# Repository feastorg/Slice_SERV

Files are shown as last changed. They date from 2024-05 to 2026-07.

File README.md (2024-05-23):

<div align="center">
  <!-- Title: -->
  <a href="https://github.com/uwo-fast">
    
  </a>
  <h2><a href="https://github.com/uwo-fast/Slice_SERV"> SERV Slice </a></h2>
  <!-- Labels: -->
  <!-- First row: -->
  <a href="https://github.com/uwo-fast/.github/blob/main/collaborating.md">
    
  </a>
  <a href="https://github.com/uwo-fast/.github/blob/main/contributing.md">
    
  </a>
  <a href="https://www.appropedia.org/Category:FAST_literature_reviews">
    
  </a>
  <a href="https://certification.oshwa.org/">
    
    <!-- img src="https://img.shields.io/badge/OSHWA-Certified-darkgreen?style=flat-square" height="20" alt="OSHWA" -->       <!-- img src="https://img.shields.io/badge/OSHWA-Pending-darkorange?style=flat-square" height="20" alt="OSHWA" -->
  </a>
  <a href="https://osf.io/">
    
  </a>
  <a href="https://doi.org">
    
  </a>
  <!-- Second row: -->
  <br>
  <a href="https://github.com/uwo-fast/Slice_SERV/blob/main/LICENSE">
    
  </a>
  <a href="https://github.com/uwo-fast/Slice_SERV">
    
  </a>
  <a href="https://github.com/uwo-fast/Slice_SERV/issues">
    
  </a>
  <a href="https://github.com/uwo-fast/Slice_SERV/network/members">
    
  </a>
  <a href="https://github.com/uwo-fast/Slice_SERV/stargazers">
    
  </a>
  <!-- Short description: -->
  <h3>Servo Motor Control Slice for BREAD.</h3>
</div>

## Introduction
[Provide a brief introduction to the project, including the motivation and goals. Explain the significance and context of the research.]

## Project Overview
[Describe the project in more detail. This section can be split into subsections if necessary.]

## Installation
[Provide instructions for installing any necessary software or hardware components.]

## Usage
[Explain how to use the project. Include examples and screenshots if applicable.]

### Basic Usage
[Provide basic usage instructions.]

### Advanced Usage
[Provide advanced usage instructions, including any optional features or configurations.]

## Documentation
[Link to the detailed documentation if available. Provide instructions on how to access and navigate the documentation.]

## Contributing
[Explain how others can contribute to the project. Include guidelines for submitting issues, pull requests, and any coding standards.]

### Code of Conduct
[Link to the project's code of conduct if available.]

## License
[State the license under which the project is distributed. Include a link to the full license text.]

## Acknowledgements
[Acknowledge any contributors, collaborators, funding sources, or organizations that supported the project.]

## Contact
[Provide contact information for the project maintainer(s) or lead researcher(s). Include an email address or a link to a contact form.]

---

<div align="center">
  <p>
    
    
  </p>
</div>

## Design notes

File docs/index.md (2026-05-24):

---
title: "Slice SERV Documentation"
description: "Overview and entry page for Slice SERV project documentation."
nav_exclude: true
---

Welcome to the Slice SERV project documentation.

## Board Renders

<figure style="display:inline-block; text-align:center; margin:10px;">
  Board Top
  <figcaption>Top</figcaption>
</figure>

<figure style="display:inline-block; text-align:center; margin:10px;">
  Board Bottom
  <figcaption>Bottom</figcaption>
</figure>

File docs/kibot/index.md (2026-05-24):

---
title: "KiBot Outputs"
description: "Index for KiBot-generated PCB artifacts."
layout: "page"
---

These are the docs & KiBot Outputs for Slice SERV

The following files were generated from the latest PCB build:

- [Schematic.pdf](./Schematic.pdf)
- [PCB.pdf](./PCB.pdf)
- [kibot.log](./kibot.log)
- [BREAD_Slice-bom.html](./BREAD_Slice-bom.html)
- [BREAD_Slice-ibom.html](./BREAD_Slice-ibom.html)

_Last updated automatically by KiBot via GitHub Actions._

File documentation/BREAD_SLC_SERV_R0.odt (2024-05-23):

# Broadly Reconfigurable and Expandable Automation Device (BREAD) – Slice Datasheet: Servo Motor Control Slice (SLC-SERV)

By: Nicholas Whisman (ngwhisma@mtu.edu) – Revision 0, on 18. May 2021

## Short Device Description

This device controls up to 5 Servo motors. As Servo motors have internal feedback control systems, this system thus has no feedback path.

## Quick Information

Device at a Glance

Short title | Servo Motor Control Slice
Part # | SLC-SERV
Repository Link | Link to OSF or other repository
Academic Paper DOI | DOI link to published paper
Device Cost | Monetary cost of the device
Assembly Difficulty | Easy, Millable
Application Area | Robotics, Controlling Machinery

Device Connections

J2 – Servo Motor 1

Pin # | Description | Rating
1 | PWM to Servo | N/A
2 | Voltage Input | Varies by Motor. Terminal can only support 10-15A
3 | GND | N/A

J3 – Servo Motor 2

Pin # | Description | Rating
1 | PWM to Servo | N/A
2 | Voltage Input | Varies by Motor. Terminal can only support 10-15A
3 | GND | N/A

J4 – Servo Motor 3

Pin # | Description | Rating
1 | PWM to Servo | N/A
2 | Voltage Input | Varies by Motor. Terminal can only support 10-15A
3 | GND | N/A

J5 – Servo Motor 4

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

J6 – Servo Motor 5

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

J7 – Power Select

Pin # | Description | Rating
1 | Power Output Pin | MUST connect one of the below to this pin.
2 | Custom Power Input | N/A
3 | Standard 12V | N/A

J8 – Custom Power Input

Pin # | Description | Rating
1 | V + | N/A
2 | GND | N/A

## Commands

Write Angle (no significant returns)
Byte: Address | Bit: 1 | Float: Target Temp | Float: Ramp Rate (d/m)
Set Up (no significant returns)
Byte: Address | Bit: 0 | Float: 0 | Float: 0

## Schematic

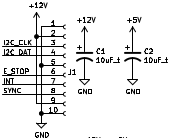
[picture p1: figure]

Figure 1: BREAD Connection Port and Power Capacitors

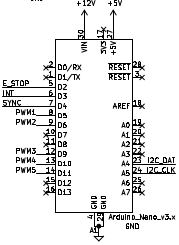
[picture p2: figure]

Figure 2: Arduino Nano

Figure 3: One of five identical Servo connection ports

Figure 4: Power Select Pins

Figure 5: Custom Power Input Port

## Bill of Materials

Designator | Description | Quantity | Cost / part | URL
J8 | 01x02 1/10” Pitch Terminal Block | 1 | 1.27 | https://www.digikey.com/short/792dvv77
J7 | 01x03 1/10” Pitch Connector Pins | 1 | 0.27 | https://www.digikey.com/short/2j42vf3d
J2-J6 | 01x03 1/10” Pitch Terminal Block | 5 | 2.06 | https://www.digikey.com/short/18bph2rj
J1 | 01x10 Female Header Pins | 1 | 0.79 | https://www.digikey.com/short/23bfwwjh
C1-2 | 1206 Packaging 10 µF Capacitor | 2 | 0.64 | https://www.digikey.com/short/qfrbqfhd
A1 | Arduino Nano | 1 | 22.00 | https://www.digikey.com/en/products/detail/arduino/A000005/2638989

## Construction & Fabrication

List any tools that are required and short guide on the order which parts should be soldered / assembled. Be sure to note any specialized methods and point out components that may easily be soldered in the incorrect orientation. Additionally include at least one picture of the assembled board (include both sides if there are components on both sides).

[Image of the assembled Circuit Board]

Fig #. Subtitle should go here.

## Configuration & Calibration

Include a list of default jumper and potentiometer positions:

Hardware Positions

- Turn P1 to be roughly 50%
- Turn P2 to be completely closed (turn clockwise until potentiometer clicks)
- Place a jumper to short out J3. Etc…

Detail any key parameters the end-user may want to adjust in the firmware, and if there are any special instructions before programming the Slice.

Tools Required For Calibration

- An oscilloscope with at least 15Mhz sampling
- A multimeter. Etc…

List all of the tools / instruments required for calibration. Provide a detailed & step by step guide on how to calibrate (or validate) each unique type of channel on the card. Include what variables in the firmware may need to be adjusted (and when). Attach a wiring diagram for each relevant calibration circuit.

[Image of the calibration circuit]

Fig #. Subtitle should go here.

## Usage & Constraints

List the relevant constraints for each type of channel on the card. These parameters may be quantities like max current, max voltage, frequency, sampling frequency, etc.

List an example wiring diagram of the slice in use, as well as some suggested applications

[Image of the example usage wiring diagram]

Fig #. Subtitle should go here.

## General Comments on Slice

This section is intended as a catch-all for any topics that are relevant to the Slice that don’t fit in any other category.

## Revision Notes

- Rev 0 – Initial document release (DATE HERE)

SLC-SERV Datasheet – Revision 0

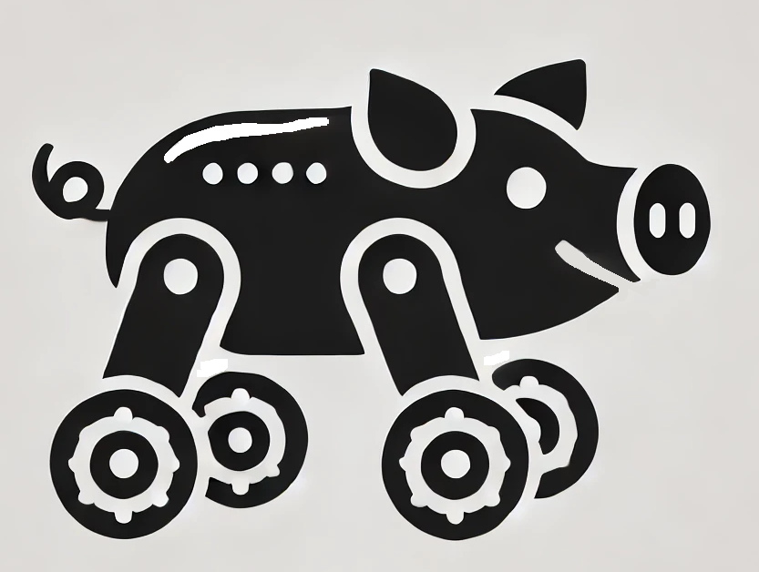
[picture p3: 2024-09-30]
hardware/servo-piggie.png

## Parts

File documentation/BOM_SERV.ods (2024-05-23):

Id | Designator | Package | Quantity | Designation | Supplier and ref
1 | J8 | TerminalBlock_TE_282834-2_1x02_P2.54mm_Horizontal | 1 | Screw_Terminal_01x02 | https://www.digikey.ca/en/products/detail/on-shore-technology-inc/OSTVN02A150/1588862
2 | J7 | PinSocket_1x03_P2.54mm_Vertical | 1 | Conn_01x03_Male | https://www.digikey.ca/en/products/detail/sullins-connector-solutions/PREC003SAAN-RC/2774851
3 | J6,J5,J4,J3,J2 | TerminalBlock_TE_282834-3_1x03_P2.54mm_Horizontal | 5 | Screw_Terminal_01x03 | https://www.digikey.ca/en/products/detail/on-shore-technology-inc/OSTVN03A150/1588863
4 | C1,C2 | C_2312 | 2 | 10uF_t | https://www.digikey.ca/short/qfrbqfhd
5 | A1 | Arduino_Nano | 1 | Arduino_Nano_v3.x | https://www.digikey.ca/en/products/detail/arduino/A000005/2638989
6 | J1 | PinSocket_1x10_P2.54mm_Horizontal | 1 | Conn_01x10_Female | https://www.digikey.ca/en/products/detail/sullins-connector-solutions/PPPC101LGBN-RC/775943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

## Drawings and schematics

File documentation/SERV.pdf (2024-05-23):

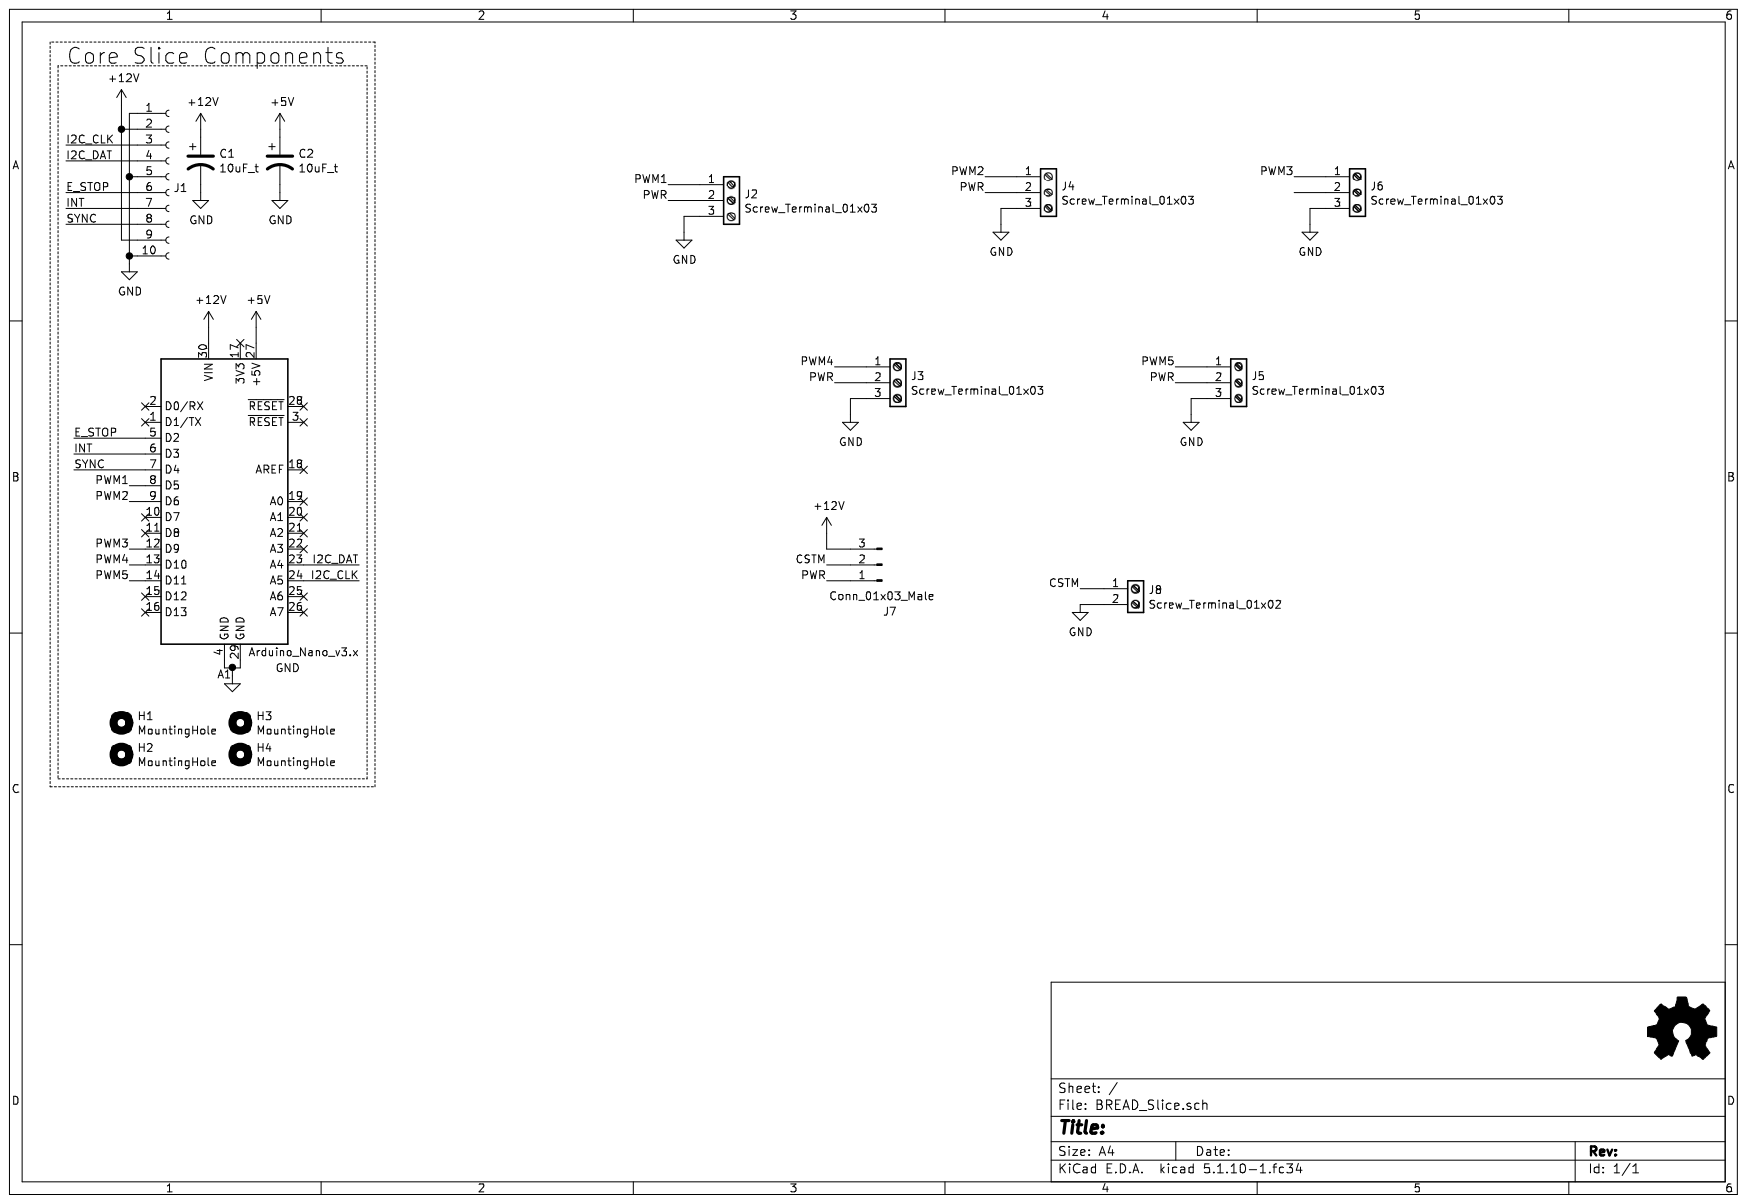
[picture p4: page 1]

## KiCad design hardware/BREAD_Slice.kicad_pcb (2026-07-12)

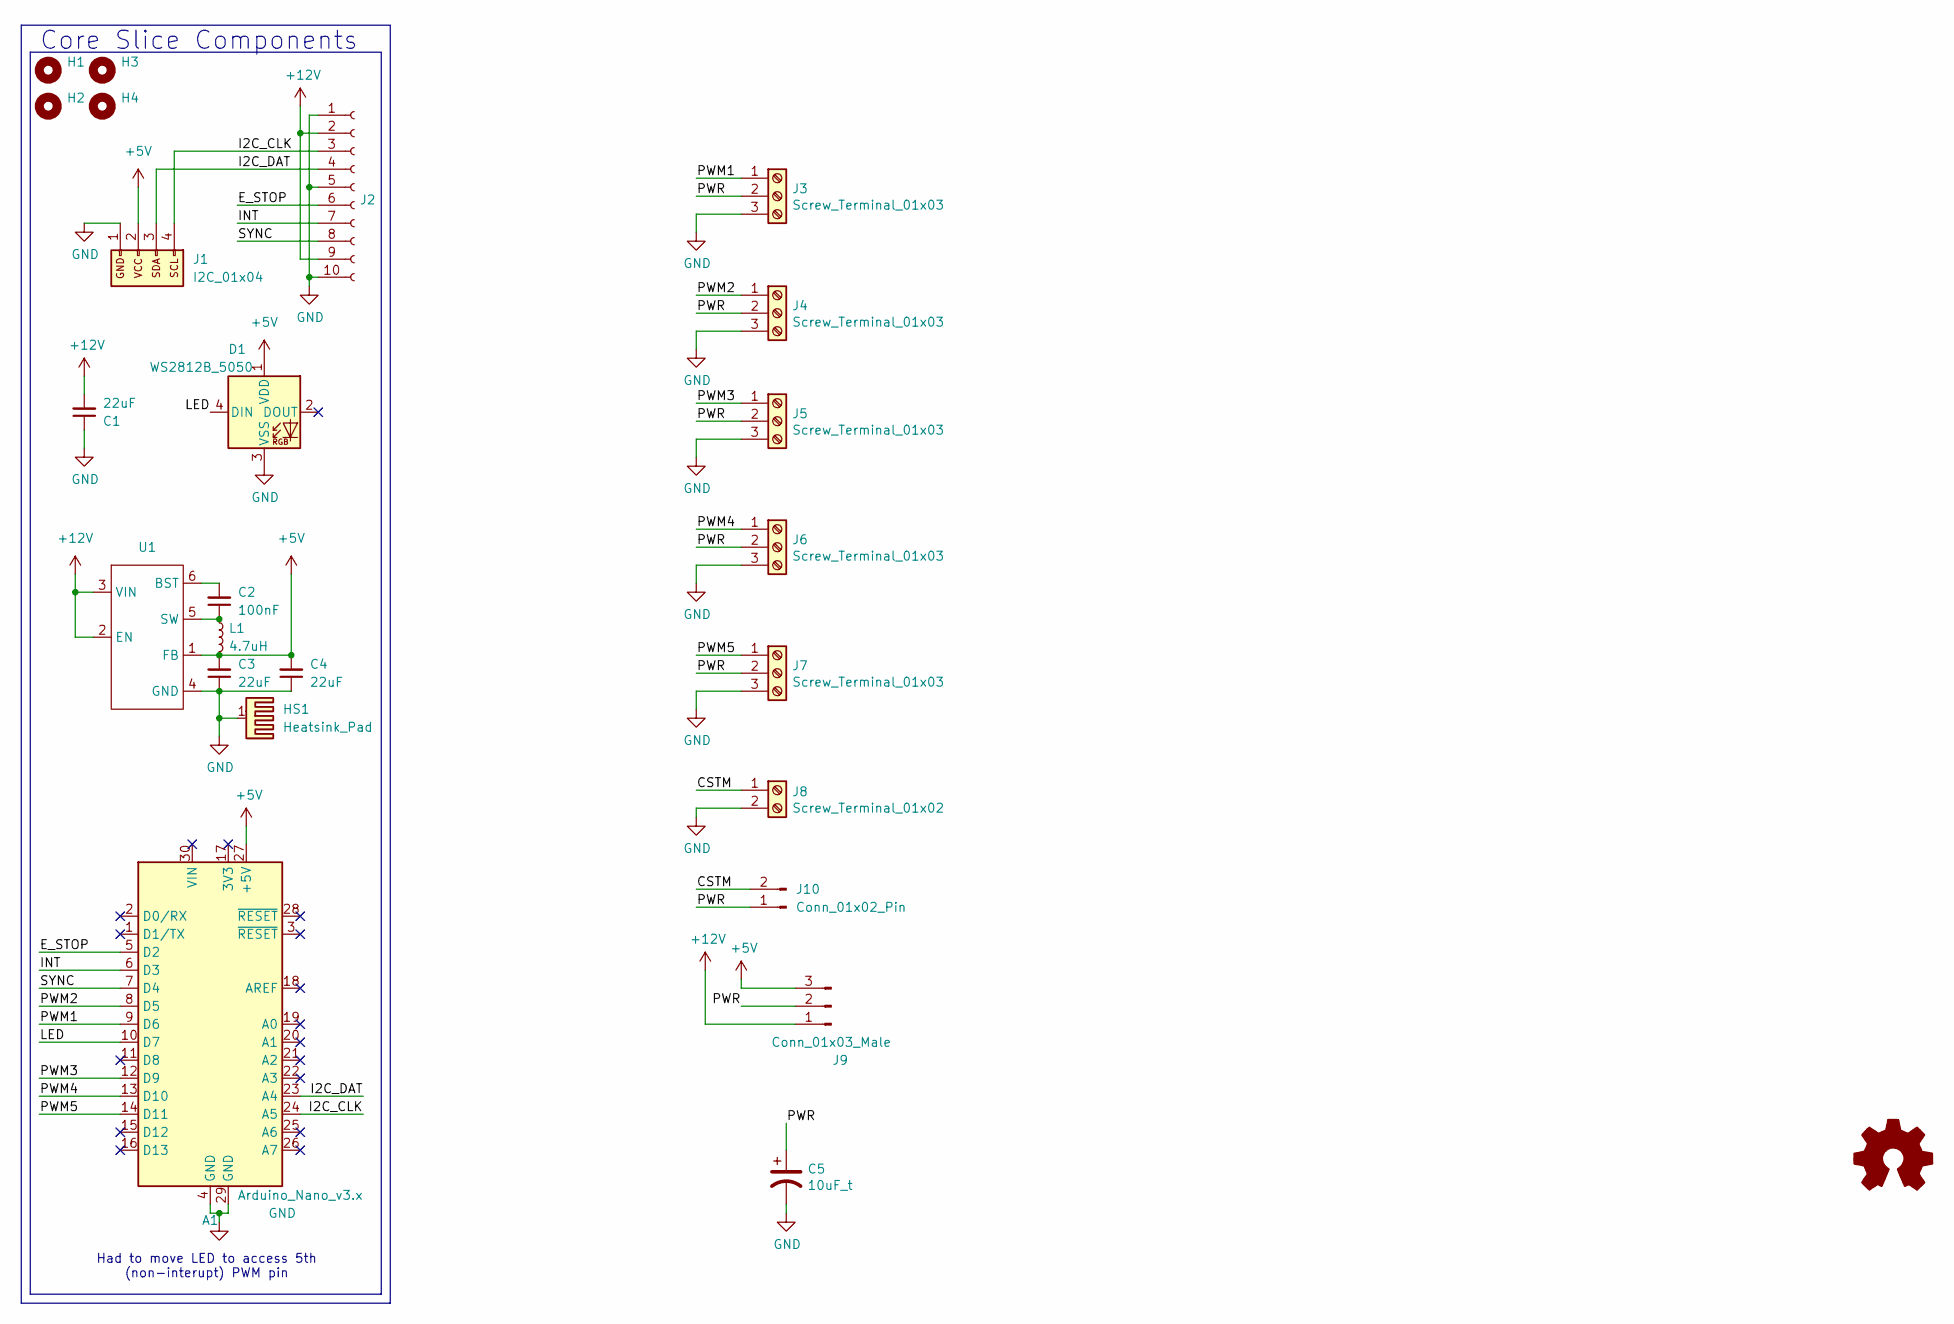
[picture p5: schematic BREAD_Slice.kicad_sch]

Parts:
A1: Arduino_Nano_v3.x; Arduino_Nano
C1, C3, C4: 22uF; C_1206_3216Metric
C2: 100nF; C_1206_3216Metric
C5: 10uF_t; C_2220_5750Metric_Pad1.97x5.40mm_HandSolder; Part # T491C106K025AT
D1: WS2812B_5050; WS2812-5050-4PIN
H1, H2, H3, H4: MountingHole; MountingHole_5mm
HS1: Heatsink_Pad; Thermal_Pad
J1: I2C_01x04; JST_SH_SM04B-SRSS-TB_1x04-1MP_P1.00mm_Horizontal
J2: Conn_01x10_Female; PinSocket_1x10_P2.54mm_Horizontal
J3, J4, J5, J6, J7: Screw_Terminal_01x03; TerminalBlock_Phoenix_MPT-0,5-3-2.54_1x03_P2.54mm_Horizontal
J8: Screw_Terminal_01x02; TerminalBlock_Phoenix_MPT-0,5-2-2.54_1x02_P2.54mm_Horizontal
J9: Conn_01x03_Male; PinSocket_1x03_P2.54mm_Vertical
J10: Conn_01x02_Pin; PinSocket_1x02_P2.54mm_Vertical
L1: 4.7uH; L_1210_3225Metric
U1: TSOT-23-6

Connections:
+5V: A1.27 (+5V), C3.2, C4.2, D1.1 (VDD), J1.2, J9.3, L1.2, U1.1 (FB)
+12V: C1.2, J2.2, J2.9, J9.1, U1.2 (EN), U1.3 (VIN)
/CSTM: J8.1, J10.2
/E_STOP: A1.5 (D2), J2.6
/I2C_CLK: A1.24 (A5), J1.4, J2.3
/I2C_DAT: A1.23 (A4), J1.3, J2.4
/INT: A1.6 (D3), J2.7
/LED: A1.10 (D7), D1.4 (DIN)
/PWM1: A1.9 (D6), J3.1
/PWM2: A1.8 (D5), J4.1
/PWM3: A1.12 (D9), J5.1
/PWM4: A1.13 (D10), J6.1
/PWM5: A1.14 (D11), J7.1
/PWR: C5.1, J3.2, J4.2, J5.2, J6.2, J7.2, J9.2, J10.1
/SYNC: A1.7 (D4), J2.8
GND: A1.4 (GND), A1.29 (GND), C1.1, C3.1, C4.1, C5.2, D1.3 (VSS), HS1.1, J1.1, J2.1, J2.5, J2.10, J3.3, J4.3, J5.3, J6.3, J7.3, J8.2, U1.4 (GND)
unnamed: C2.2, U1.6 (BST)
unnamed: C2.1, L1.1, U1.5 (SW)

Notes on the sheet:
Had to move LED to access 5th (non-interupt) PWM pin
Core Slice Components

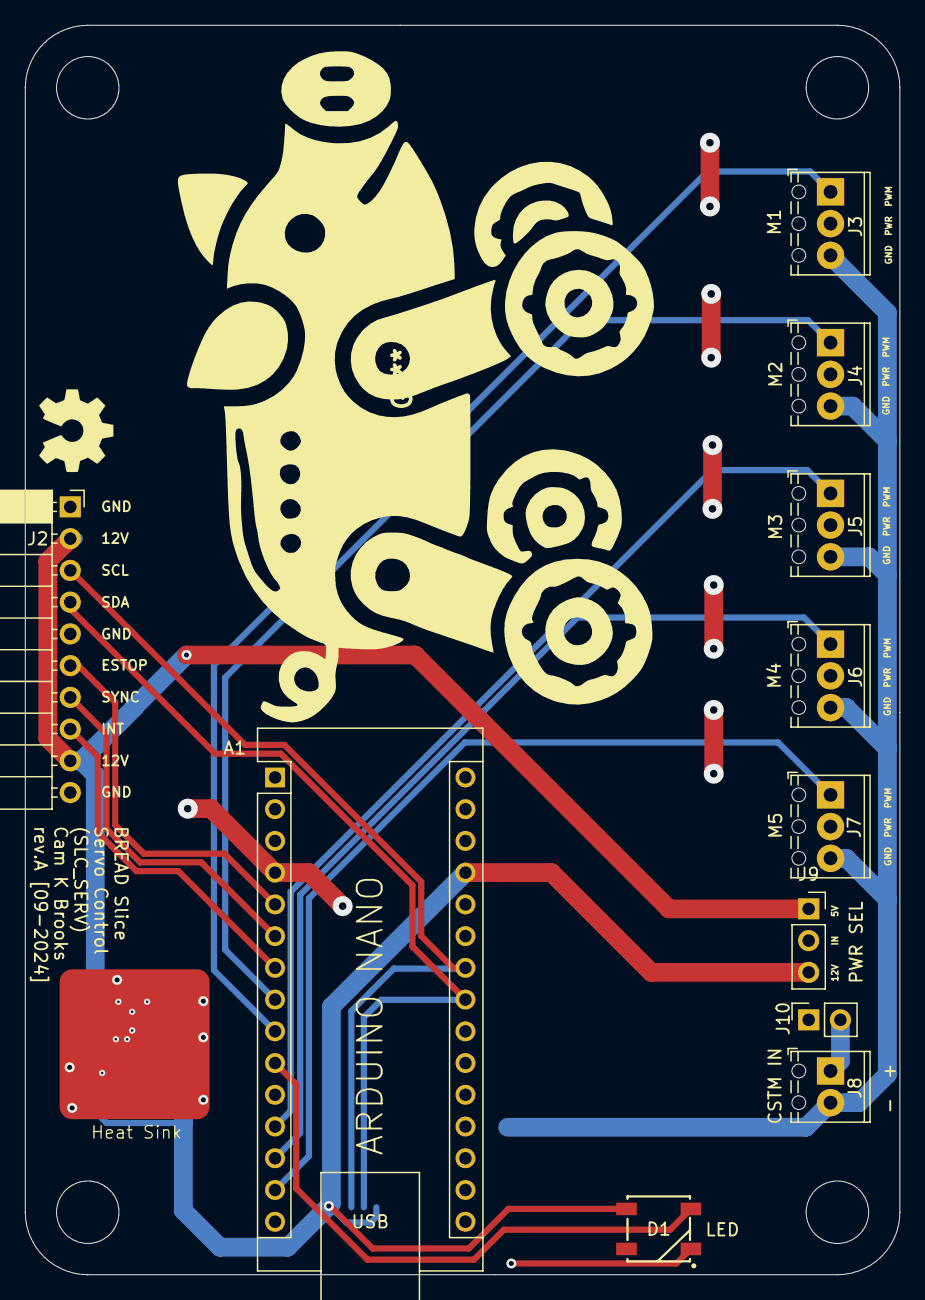
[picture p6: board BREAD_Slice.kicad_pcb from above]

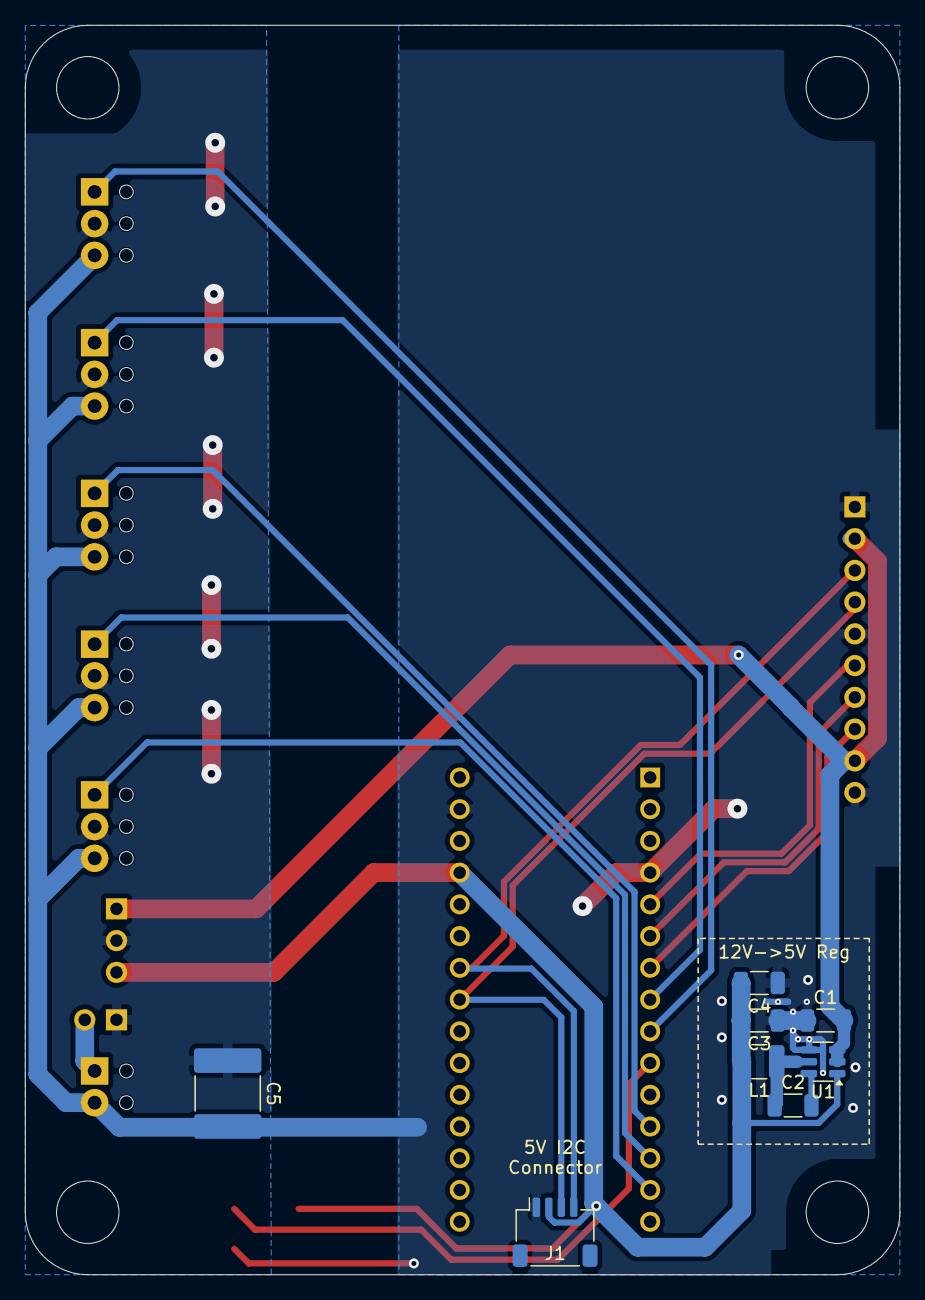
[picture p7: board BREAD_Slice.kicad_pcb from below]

Board: 2 copper layers, 70.0 x 100.0 mm, 25 parts (8 on the bottom side), 18 nets.

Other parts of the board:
Logo1: Logo_Open_Hardware_Small; OSHW-Symbol_6.7x6mm_SilkScreen

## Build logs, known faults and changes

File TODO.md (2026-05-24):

# TODO

## Pass 1 — CI Pipeline

- [x] Pipeline added
- [x] ERC: FAIL — 2 errors (power_pin_not_driven x2)
- [x] DRC: PASS
- [ ] Fab: SKIPPED (blocked by ERC pre-flight)
- [ ] gen-kibot-index: SKIPPED
- [ ] deploy-pages: SKIPPED

## Pass 2 — Pre-Fab Review

- [ ] Fix 2x power_pin_not_driven ERC errors
- [ ] Verify BOM completeness and sourcing
- [ ] Confirm board outline and mounting holes
- [ ] Footprint verification against datasheets
- [ ] Design review sign-off

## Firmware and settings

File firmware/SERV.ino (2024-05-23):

/*
 * Currently intended for testing. Code wipes each servo through 180 degrees and back
 */

#include <Servo.h>

#define serv1Pin 5
#define serv2Pin 6
#define serv3Pin 9
#define serv4Pin 10
#define serv5Pin 11

Servo servo1;
Servo servo2;
Servo servo3;
Servo servo4;
Servo servo5;

void setup() {
  // put your setup code here, to run once:

  servo1.attach(serv1Pin);
  servo2.attach(serv2Pin);
  servo3.attach(serv3Pin);
  servo4.attach(serv4Pin);
  servo5.attach(serv5Pin);
  
  servo1.write(0);
  servo2.write(0);
  servo3.write(0);
  servo4.write(0);
  servo5.write(0);
  
  delay(500);
}

void loop() {
  // put your main code here, to run repeatedly:

  for(int i=0; i<=180; i++){
    servo1.write(i);
    servo2.write(i);
    servo3.write(i);
    servo4.write(i);
    servo5.write(i);
    delay(5);
  }
  for(int i=180; i>=0; i--){
    servo1.write(i);
    servo2.write(i);
    servo3.write(i);
    servo4.write(i);
    servo5.write(i);
    delay(5);
  }
}

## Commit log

2024-09-13 changed custom selection method to be correct and offer 5V, new BREAD core
    [BREAD_Slice-B_Cu.gbr, BREAD_Slice-B_Mask.gbr, BREAD_Slice-B_SilkS.gbr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]
2024-09-30 JLCPCB order rev-A
    [BREAD_Slice-B_Cu.gbr, BREAD_Slice-B_Mask.gbr, BREAD_Slice-B_Paste.gbr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]
2026-07-12 chore(hw): migrate KiCad files to the KiCad 10 format
    Via `kicad-cli sch upgrade` / `pcb upgrade` (bread-infra
    scripts/upgrade_kicad10.sh). Verified lossless: identical netlist, footprint
    positions and routing.
    Note `sch upgrade` does not cascade into hierarchical sub-sheets, so every
    .kicad_sch is upgraded individually -- upgrading only the root sheet leaves
    sub-sheets on the old format, which looks migrated and is not.
    [BREAD_Slice.kicad_pcb, BREAD_Slice.kicad_sch]
2026-07-12 fix(hw): fail DRC on schematic/PCB footprint mismatch
    KiCad's stock default severity for footprint_symbol_mismatch is `warning`
    (board_design_settings.cpp:189), and KiBot's DRC preflight only fails on
    errors. So `schematic_parity: true` ran the check and could never fail it --
    a mismatch was reported on every CI run for months, buried in ~100 warnings,
    and every run went green.
    Raising it to `error` makes the parity gate real.
2026-07-12 chore: gitignore KiCad 10 local history
    KiCad 10 added a Local History feature. On first save it creates
    <project>/.history and calls git_repository_init() on it, so the directory is
    a nested git repository. KiCad writes a .gitignore inside it, but that governs
    KiCad's own history repo -- this repo still sees an embedded repository and
    reports it untracked. Committing it would add a broken gitlink.
2026-07-12 fix(hw): re-point stale library nicknames
    These parts exist in KiCad-Master-Lib; the boards referenced libraries that no
    longer exist (kml-custom, KML-Custom, and SparkFun libraries that never
    contained the part) or names the library has since changed.
    KiCad embeds footprint geometry in the .kicad_pcb, so the boards rendered and
    fabricated correctly and the rot stayed invisible -- it only surfaces on
    update-from-library, or when a generator tries to resolve a nickname.
    Nickname/name only. No geometry is changed:
    KML-Custom:Thermal Pad -> KMLib_Mounting:Thermal_Pad
    SparkFun-DiscreteSemi:AP63205 -> KMLib_IC_Power:AP63205WU-7_Buck_Regulator
    SparkFun-LED:WS2812-5050-4PIN -> KMLib_IC_SMD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
    [BREAD_Slice.kicad_pcb, BREAD_Slice.kicad_sch]
2026-07-12 chore: stop tracking .kicad_prl
    KiCad rewrites .kicad_prl on every project open -- open sheet, zoom level,
    selection filter. It is per-developer local state, not design intent, so
    tracking it means the working tree goes dirty every time anyone opens the board.
2026-07-12 ci: gate on board validation and run on pull requests
    - add the validate-board job: KiCad 10 format, a real (error-severity) DRC
    parity gate, every library reference resolving, un-swapped Makefile targets,
    and .history/.kicad_prl gitignored. Green means the board is done.
    - run on pull_request, not just push to main. Hardware checks previously ran
    only AFTER a change had merged: they could report that main was broken, but
    never stop it from breaking. A gate that only fires post-merge is a
    notification, not a gate.
    - pin bread-infra to v1.0.0 rather than @main, so a bread-infra commit cannot
    silently change what this PR is gated on.
2026-07-12 chore: gitignore KiCad 10 generated and lock files
    KiCad 10 adds design-block libraries and generates a design-block-lib-table
    alongside fp-lib-table and sym-lib-table. Like those, it holds absolute paths,
    so it is machine-local and generated -- never committed.
    Also ignores KiCad's project lock file (~<project>.kicad_pro.lck), written
    whenever a project is open.
    The existing .gitignore predates KiCad 10 and covered neither, so simply opening
    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
2026-07-12 fix(hw): repair symbol sub-unit name prefixes
    The library re-point renamed symbols in lib_symbols from LIB:OLD to LIB:NEW,
    but a symbol's sub-units carry the bare item name:
    (symbol "KMLib_IC_Power:AP63205WU-7_Buck_Regulator"
    (symbol "AP63205_0_1" ...) <- still the old prefix
    KiCad requires every sub-unit to be named "<parent item>_<unit>_<style>", so any
    symbol whose ITEM name changed (not merely its library) failed to load:
    Invalid symbol unit name prefix AP63205_0_1
    Rename each sub-unit to match its parent. Nickname-only re-points were never
    affected -- their item name is unchanged.
    Note kicad-cli reports "Failed to load schematic" and still EXITS 0, so this was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
    [BREAD_Slice.kicad_sch]
2026-07-12 ci: pin bread-infra v1.1.0
    v1.1.0 adds the schematic-load check. kicad-cli prints 'Failed to load
    schematic' and still exits 0, so an unloadable schematic scored as zero ERC
    violations -- 34 boards were unopenable while every automated check said they
    were fine. validate-board now runs in the KiCad container and actually loads
    every sheet.
2026-07-13 fix(hw): use the canonical 2-layer KiBot config
    config.kibot.yaml had drifted into five variants across the fleet. Three differed
    only in trailing comments; the two real variants are 2-layer and 4-layer.
    Adopts bread-infra templates/config.kibot.2-layer.yaml, chosen from the board's
    actual copper layer count (2).
    Also pins bread-infra to v1.2.0, which adds a validate-board check that a board
    must plot every copper layer it has.
